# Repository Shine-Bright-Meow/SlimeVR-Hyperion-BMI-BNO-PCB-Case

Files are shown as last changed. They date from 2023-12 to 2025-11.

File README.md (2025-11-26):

> [!NOTE]
>I have a new carrier PCB which is smaller and more optimized than the Hyperion PCB. The entire assembly with case for the 503759 battery is smaller and lighter than the Hyperion one in this repository. The PCB and Case files for meowCarrier PCB can be found here: <https://github.com/Shine-Bright-Meow/meowCarrier/blob/main/README.md>

# SlimeVR Hyperion Multi-IMU BMI BNO Case and PCB

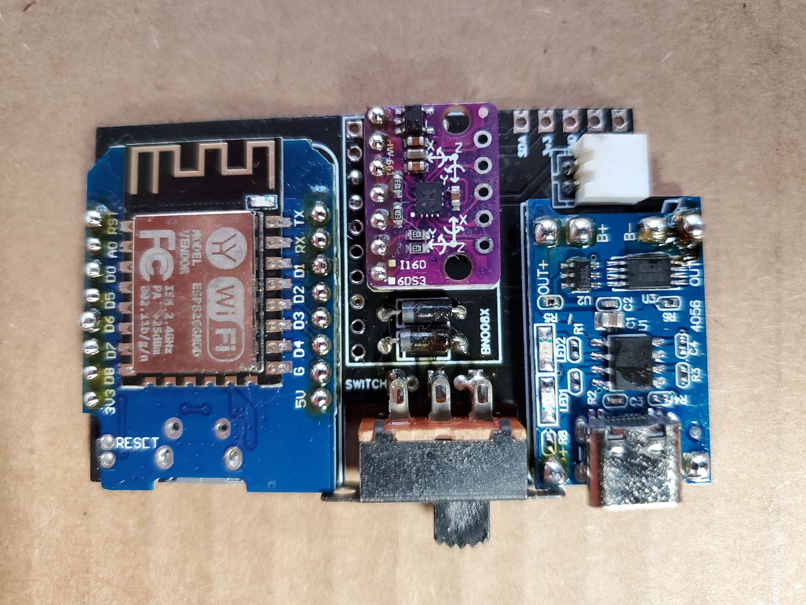
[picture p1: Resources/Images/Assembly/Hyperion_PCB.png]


## Purchasing Guide
### Recommended Components (PCB)
Choose either ICM-45686/LSM6DSV (Performance) and LSM6DSR (Budget/Value) from the list below; not all three.

| Component | Variant | Link |
| --- | --- | --- |
| WeMos D1 Mini | Micro or Type-C (not V4.0.0) | <https://www.aliexpress.us/item/2251832465432818.html> |
| TP4056 | 18650 Micro or Type-C | <https://www.aliexpress.us/item/2251832290307200.html> |
| ICM-45686 | N/A | <https://shop.slimevr.dev/products/slimevr-mumo-breakout-module-v1-icm-45686-qmc6309> |
| LSM6DSR | N/A | <https://moffshop.deyta.de/products/lsm6dsr> |
| LSM6DSV | N/A | <https://moffshop.deyta.de/products/lsm6dsv-module> |
| SS22F32/DPDT 2P2T Switches | N/A | <https://www.aliexpress.us/item/2251832789220847.html> |
| 1/4W Metal Film Resistor | 180**K** | <https://www.aliexpress.us/item/3256803737288214.html> |
| Schottky Rectifier Diode | 1N5817 | <https://www.aliexpress.us/item/2255800018624086.html> |
| Header Pins | 2.54mm | <https://www.aliexpress.us/item/3256805804439042.html> |
| JST PH 2.0mm Connector | Right Angle/Side Entry & 2-Pins (2P) | <https://www.aliexpress.us/item/3256804769340392.html> |
| Lithium Polymer Ion Battery | 503759 with Connector (PH) | <https://www.aliexpress.us/item/3256805125875396.html> |

> [!IMPORTANT]
> Purchase 30% more boards (WeMos D1 Mini, TP4056, and LSM6DSR/LSM6DSV/ICM-45686 than what is needed. There is the possibility that components are dead on arrival or get damaged during assembly/soldering.

> [!NOTE]
> One order of Resistors, Diodes, Header Pins, Switches, and PH 2.0mm Connectors is enough for the entire project.

> [!NOTE]
> The SlimeVR DIY Community recommends buying boards from the following sellers on AliExpress: Win Win, Aitexm, or Tenstar Robot.

> [!NOTE]
> Type-C Ports are more durable. As for charging, USB-C to USB-C Power Delivery doesn't work. Use USB-A to USB-C cables to charge trackers.

> [!IMPORTANT]
> When purchasing components, some have multiple variants on the same product page like Diodes and Resistor. Be sure to select the correct one.

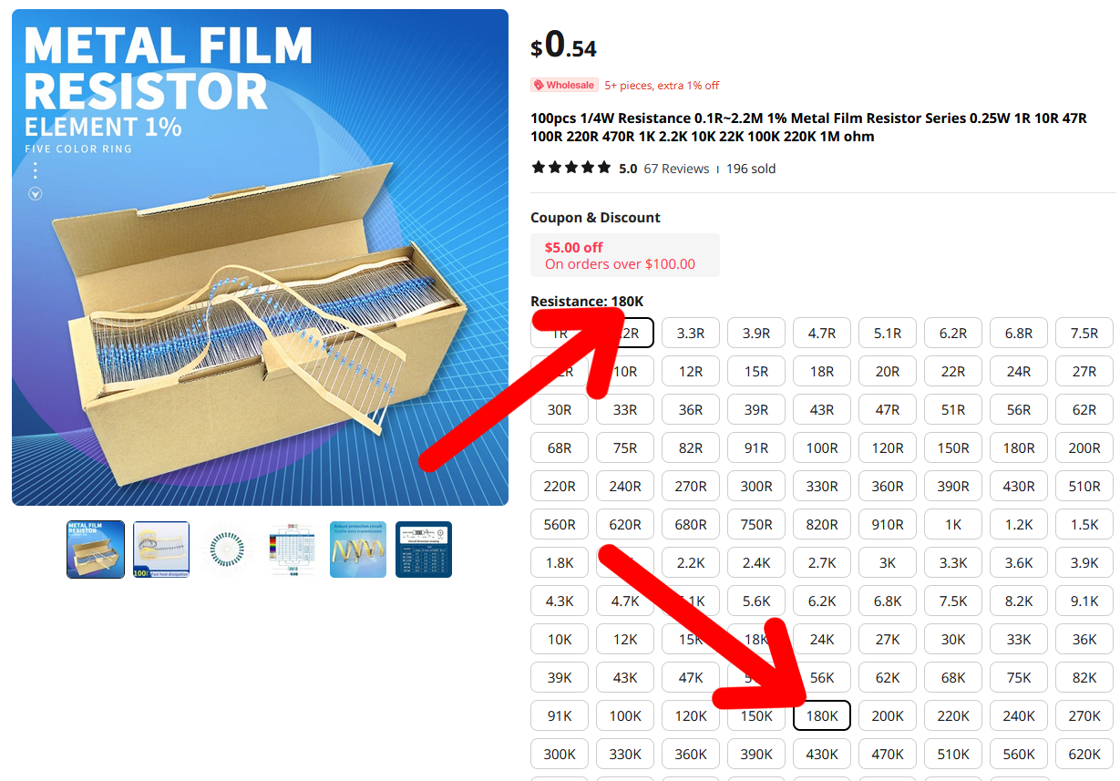
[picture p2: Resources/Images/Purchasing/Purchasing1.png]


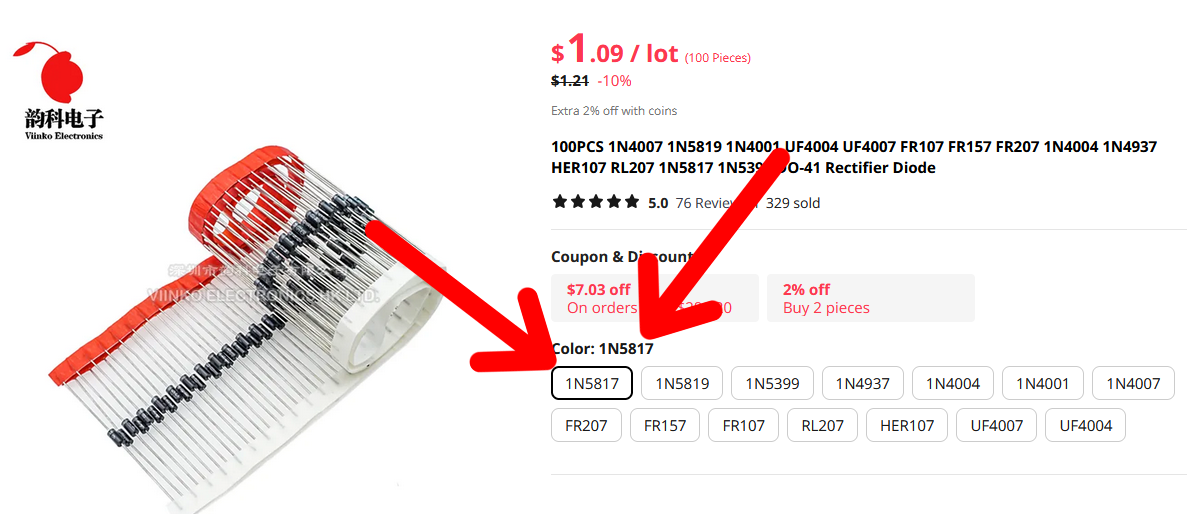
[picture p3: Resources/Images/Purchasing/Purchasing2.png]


> [!TIP]
> In your AliExpress Cart, you can verify that you selected the correct variant of the component here.

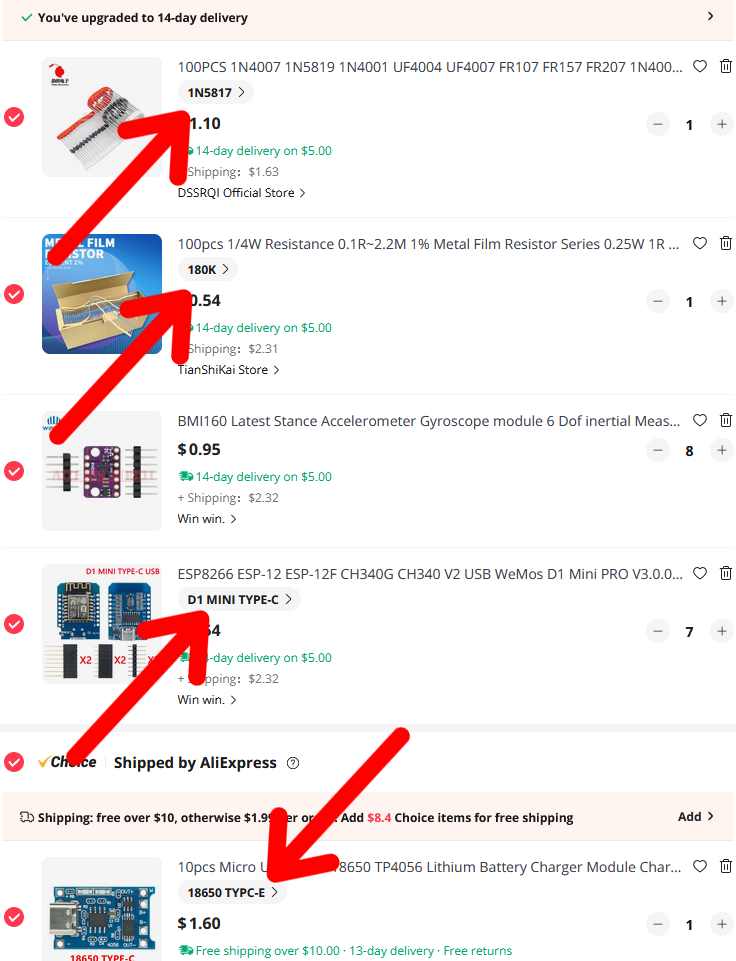
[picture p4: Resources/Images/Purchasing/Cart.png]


### Optional Components (PCB)
| Component | Variant | Link |
| --- | --- | --- |
| JST XH 2.54mm Connector | Right Angle/Side Entry & 4-Pins(LSM6DSR/LSM6DSV/ICM-45686)/5-Pins(BNO085) | <https://www.aliexpress.us/item/2251832822174658.html> |
| JST XH 2.54mm Connector with Female Cable | Right Angle/Side Entry & 4-Pins(LSM6DSR/LSM6DSV/ICM-45686)/5-Pins(BNO085)| <https://www.aliexpress.us/item/2255799934230488.html> |
| Sheathed Wire Cable | 28AWG & 4Cores(LSM6DSR/LSM6DSV/ICM-45686)/5Cores(BNO085) | <https://www.aliexpress.us/item/2255800384086289.html> |

> [!NOTE]
> I recommend using Sheathed Wire Cable and soldering it directly onto the PCB for extensions. (JST XH Connector is not needed for this method) Usually, less connection issues than using connectors.

### Recommended Consumables/Tools
| Component | Variant | Link |
| --- | --- | --- |
| Soldering Iron | Any with BC2 Tip | <https://www.aliexpress.us/item/3256805553022893.html> |
| Solder Sucker| SS-02 or SS-02 Clone | <https://www.aliexpress.us/item/3256805437410900.html> |
| Desoldewring Iron| Choose your electrical outlet | <https://www.aliexpress.us/item/3256804929123151.html> |
| Rosin Flux | Liquid or Gel Type | N/A |

> [!NOTE]
> You will have a much better soldering experience with better tools. These are my recommended (but still on a budget) Soldering Iron and Solder Sucker if you don't have these tools or better already. They will work much better than those Amazon $10-20 soldering kits/iron.

> [!NOTE]
> The Soldering Iron listed requires an USB Type-C Power Delivery charging block of 60W or higher.

### Recommended Components (Case)
| Component | Variant | Link |
| --- | --- | --- |
| Trilancer Elastic Cinch Straps | See note below | <https://www.amazon.com/dp/B099RNRT7Z> |
| GoPro Chest Mount Harness | See note below | <https://www.aliexpress.us/item/3256805774922789.html> |

> [!NOTE]
> 12in works for ankles. 18in for thinner thighs and 24in for thicker thighs. Chest (if not using GoPro Chest Harness) and Hips can be done by doubling up on 18in/24in straps. Choose what you need for your body and how many trackers you are planning to make. 3 Size Combo and either 18in/24in package would be a start.

> [!NOTE]
> There are 2 types of GoPro Chest Mount Harness. One that clips in and the other one fasten by a bolt. Be sure to purchase one one for the case you are 3D Printing.

### Ordering PCBs from JLCPCB
1. Download the Gerber file from [here](https://github.com/Shine-Bright-Meow/SlimeVR-Hyperion-BMI-BNO-PCB-Case/raw/main/PCB/Gerber_PCB_Hyperion%20SlimeVR%20Multi-IMU%20BMI%20BNO.zip).
2. Go to [JLCPCB](https://jlcpcb.com).
3. Click on "Add Gerber File" and upload the zip Gerber file.

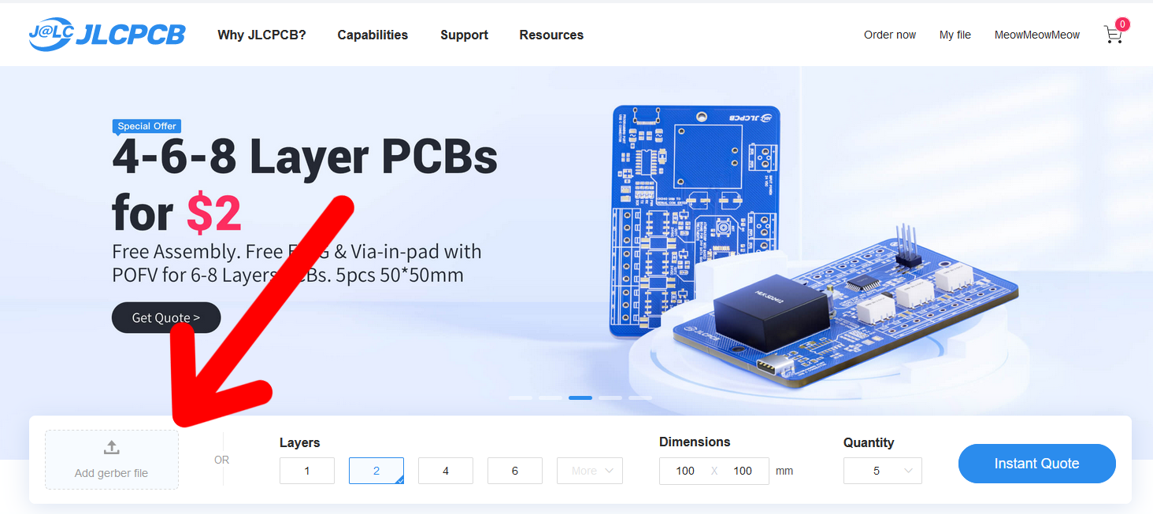
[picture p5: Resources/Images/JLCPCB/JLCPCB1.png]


4. Select the PCB Qty and PCB Color of your choice. Select 1.0 for PCB Thickness and select "Specify a location" for Remove Order Number.

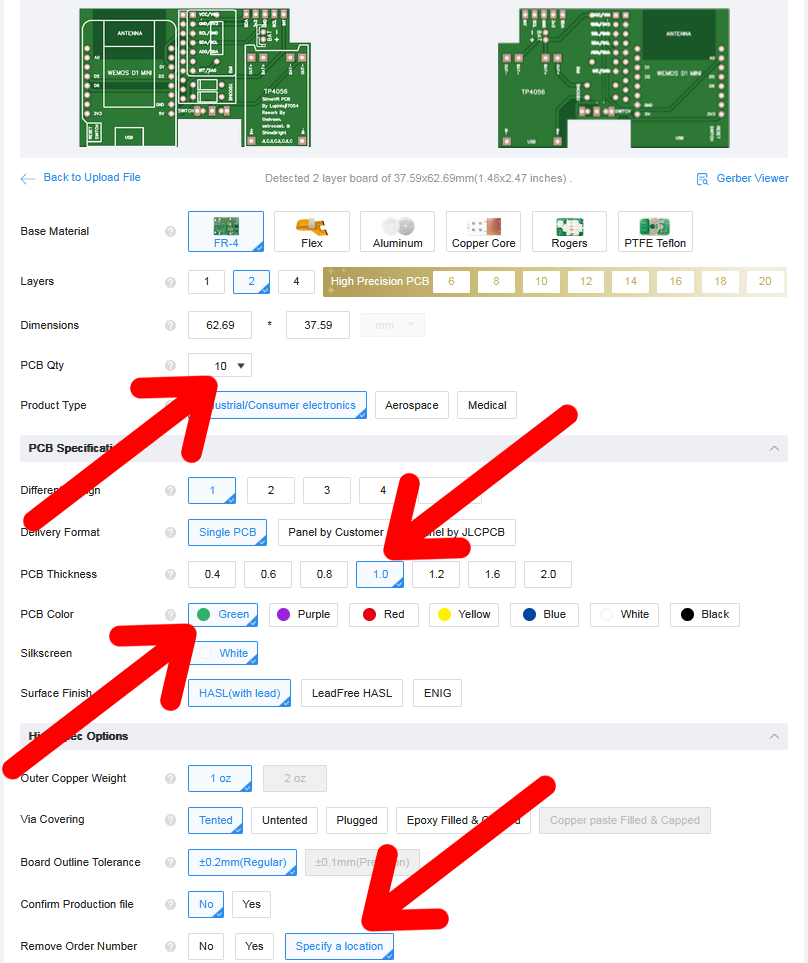
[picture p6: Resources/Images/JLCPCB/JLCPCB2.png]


> [!IMPORTANT]
> Set PCB Thickness to 1.0 if you are using the case from this repository.

> [!NOTE]
> When ordering PCBs, please check if the case recommends a certain thickness it is designed for. For example, the case in this repository and Cheesecake recommend 1.0mm Thickness. If unspecified, the default 1.6mm will do. The case in this repository has loose tolerances incase you ordered the default 1.6mm thickness, it will work okay.

> [!NOTE]
> JLCPCB usually produces Green colored PCB the quickness. Other colors have additional days added.

> [!NOTE]
> For Remove Order Number, when "Specify a location" is selected, it will the order number will be printed at where the text **JLCJLCJLCJLC** is located. In this case, at the bottom of the TP4056 module footprint.
5. Click to View Cart.

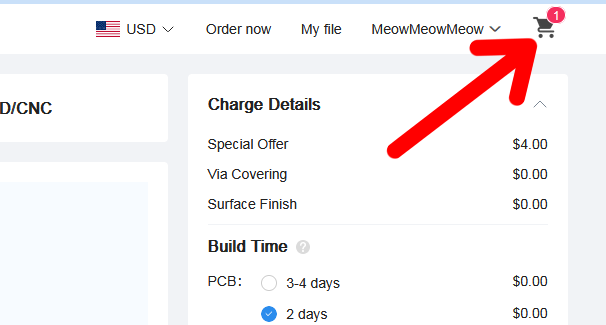
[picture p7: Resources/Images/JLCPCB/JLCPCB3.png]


6. Click Secure Checkout.

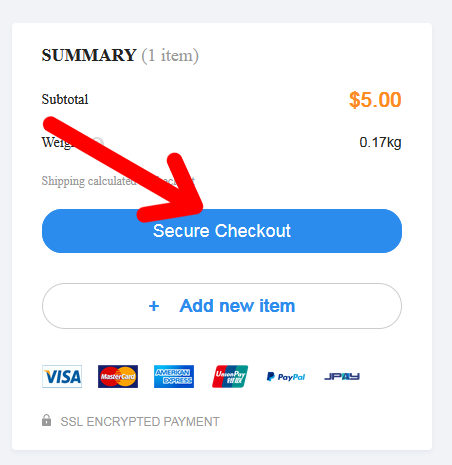
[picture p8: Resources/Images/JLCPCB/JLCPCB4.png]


## Soldering/Assembly Guide

### Written Guide

> [!WARNING]
> Please work at a well ventilated area. It is recommended to use a fume extractor if working indoors. If you do not have one, use a fan to blow fumes/smoke away from your face.

> [!WARNING]
> It is recommended to use eye production. Especially when splitting header pins apart with a cutter and when trimming down header pins and ends of resistors/diodes.

> [!WARNING]
> If working with leaded solder, be sure to wash your hands when you are done including under your fingernails. Wipe down and vacuum the floors and surfaces of your workspace and anything you may have cross-contaminated.

> [!TIP]
> Using external flux (preferably Rosin) will allow solder to flow to automatically flow into the correct area.

> [!TIP]
> A wooden clothespin can be used to hold the boards together while soldering.

> [!NOTE]
> Resistor and Diodes

#### Battery Connector
##### With JST PH 2.0mm 2P Connector
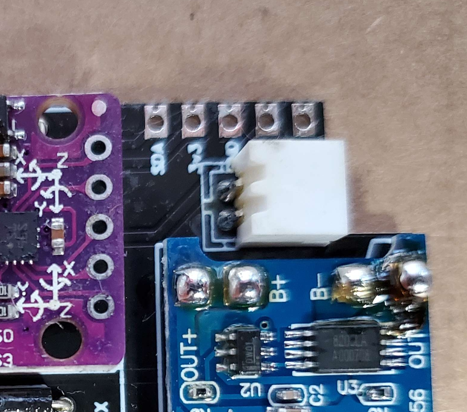
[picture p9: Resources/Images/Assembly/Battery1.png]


1. Place connector as positioned on the photo. The opening should be facing teh cutout and the smooth side should be on top and the slotted side should e against the PCB.
2. Solder the 2 pins in the back.
3. Trim excess length of pins using a flush cutter. Use your wire cutter if you don't have a flush cutter and cut as close the the PCB as you can.

> [!NOTE]
> If you got straight pin connectors, you can bend them 90 degrees, so they will work. There will be a little less pin length sticking out from the back to solder and there is a chance of you snapping them. You should have plenty of connectors incase the pin snaps.

##### Without JST Connector
> [!IMPORTANT]
> This step should be done last after the entire board is assembled and after you verified that the solder joints all look fine.

> [!IMPORTANT]
> Do not solder the battery leads to the holes of the PCB. The angle will put stress on the wire and solder joint and will eventually break off.

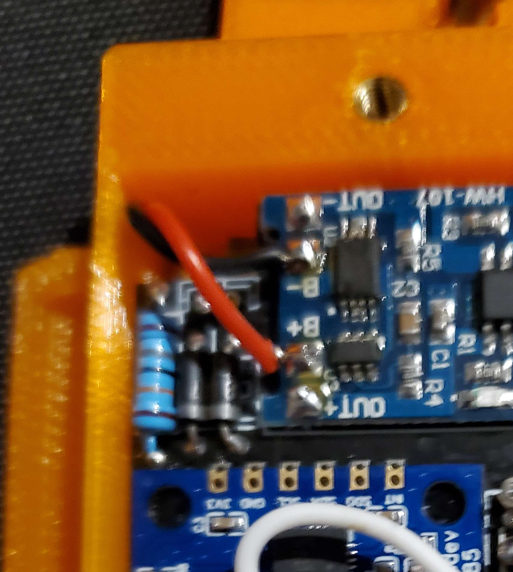
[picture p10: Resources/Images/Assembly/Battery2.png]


1. Strip the battery leads they are not exposed already.

> [!WARNING]
> Do not let the exposed battery leads make contact with each other.

2. Place your soldering iron on the BAT+ pad and melt the solder.
3. Place the **RED** battery lead in the molten solder pad and let it cool off.
4. Repeat the process for the BAT- pad and the **BLACK** battery lead.

##### Diodes
> [!NOTE]
> Make sure the diode is facing the correct direction and has the correct values. It will not be easy to access the diode once you solder the IMU above it.

1. Verify that the diodes are 1N5817. You can find the text on the body.

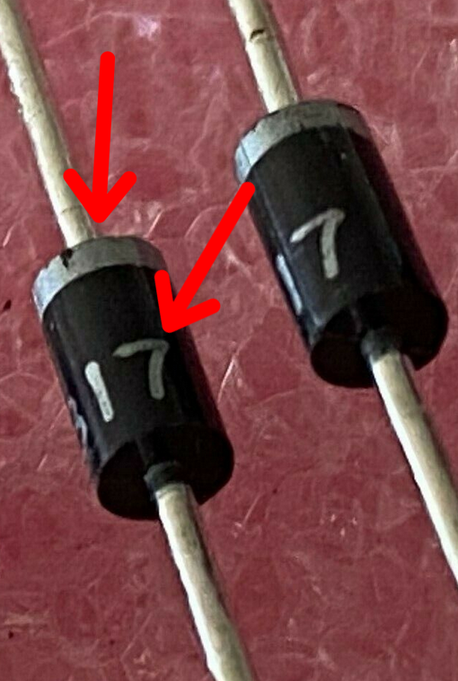
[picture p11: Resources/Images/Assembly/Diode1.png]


2. Place the diode's striped (grey/silver) on the narrow stripe indicated on the silkscreen.

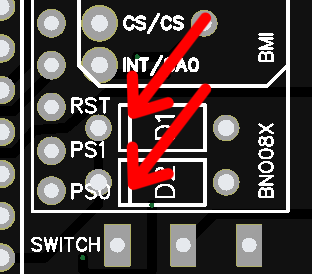
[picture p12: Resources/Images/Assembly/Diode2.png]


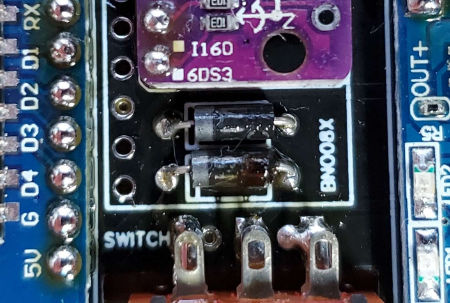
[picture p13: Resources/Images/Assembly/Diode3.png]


3. Bend the ends in 90 degrees, so it is shaped like a staple and place into the through-hole.
4. Pull the excess on the back until diode is flush with the PCB.
5. Solder ends from the back.
6. Repeat for other diode.
7. Trim excess length of pins using a flush cutter. Use your wire cutter if you don't have a flush cutter and cut as close the the PCB as you can.

##### Resistor
> [!NOTE]
> Make sure the resistor is the correct value. It will not be easy to access the resistor once you solder the IMU above it.

1. Verify the resistor is 180K. The first 4 colors should go in this order:
- Brown
- Grey
- Black
- Orange

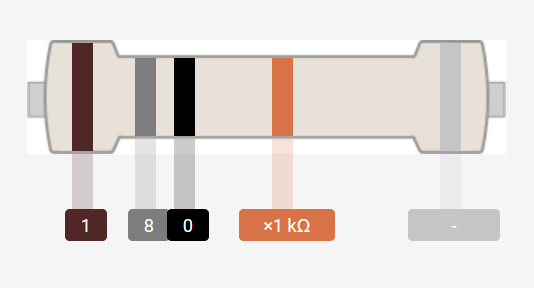
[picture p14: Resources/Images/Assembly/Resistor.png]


2. Bend the ends in 90 degrees, so it is shaped like a staple and place into the through-hole. Resistors are not polarized, so the direction does not matter.
3. Pull the excess on the back until resistor is flush with the PCB.
4. Trim excess length of pins using a flush cutter. Use your wire cutter if you don't have a flush cutter and cut as close the the PCB as you can.

#### Switch

##### DPDT 2P2T/SS22F32

##### SS12D00G3

#### Charging Board (TP4056)

#### IMU (LSM6DSR, LSM6DSV, ICM-45686)

#### MCU (WeMos D1 Mini)

### Video Guide


## Case Guide
The case consists of 3 files: Case, Lid, and Tray.

Printer Settings used:
- **Printer:** Creality CR-10 S5
- **Infill:** 100%
- **No** Rafts or Supports
- **Resolution:** 0.2mm
- **Nozzle:** 0.4mm
- Tested with PLA+ and PETG

> [!TIP]
> For stronger strap loops, print the base/bottom 4mm layers with 0% (solid) infill for just the **case** file. Printing with a zig-zap pattern instead of line will help prevent strap loops from breaking at the weak point where layers join horizontally or vertically. These are done in your Slicer.

### Case
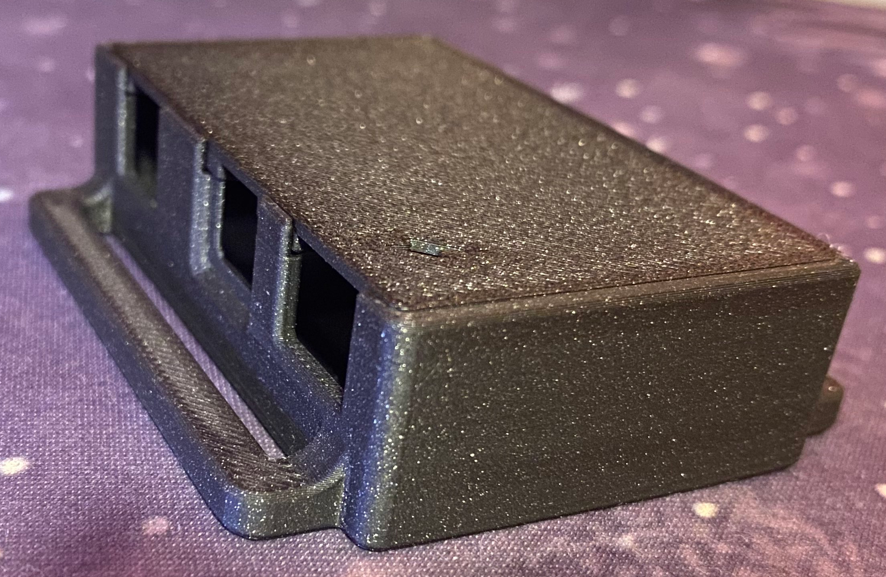
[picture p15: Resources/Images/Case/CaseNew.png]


Case Photo by Higanbana (Meia)

- **No AUX** hasa solid back portion.
- **AUX JST Cutout** has a JST XH 2.54mm 4P-Pin or 5-Pin connector in the back for extension trackers. The non-noted version is for the Multi-IMU version of the PCB and the noted version is for Lupinixx's BMI160 Version.
- **50mm Strap Loops** are the normal for fastening the tracker to your body. You can always use smaller straps.
- **GoPro Chest Harness Adapter** snaps into the harness clip from the top. It is more stable for chest tracking and won't slip down your body.

> [!IMPORTANT]
> GoPro Chest Harness Tracker will have a different IMU rotation than your other trackers.

| Battery | Variant | Link |
| --- | --- | --- |
| 503759 | 50mm Strap Loops / No AUX | [Hyperion_Lite_Case_503759.stl](https://github.com/Shine-Bright-Meow/SlimeVR-Hyperion-BMI-BNO-PCB-Case/raw/main/Case/STL/Hyperion_Lite_Case_503759.stl)|
| 503759 | 50mm Strap Loops / AUX JST Cutout | [Hyperion_Lite_Case_503759_AUX.stl](https://github.com/Shine-Bright-Meow/SlimeVR-Hyperion-BMI-BNO-PCB-Case/raw/main/Case/STL/Hyperion_Lite_Case_503759_AUX.stl) |
| 503759 | 50mm Strap Loops / AUX JST Cutout (Lupinixx) | [Hyperion_Lite_Case_503759_AUX_Lupinixx.stl](https://github.com/Shine-Bright-Meow/SlimeVR-Hyperion-BMI-BNO-PCB-Case/raw/main/Case/STL/Hyperion_Lite_Case_503759_AUX_Lupinixx.stl) |
| 503759 | GoPro Chest Harness Adapter / No AUX | [Hyperion_Lite_Case_503759_GoPro.stl](https://github.com/Shine-Bright-Meow/SlimeVR-Hyperion-BMI-BNO-PCB-Case/raw/main/Case/STL/Hyperion_Lite_Case_503759_GoPro.stl) |
| 804040 | 50mm Strap Loops / No AUX | [Hyperion_Lite_Case_804040.stl](https://github.com/Shine-Bright-Meow/SlimeVR-Hyperion-BMI-BNO-PCB-Case/raw/main/Case/STL/Hyperion_Lite_Case_804040.stl)|
| 804040 | 50mm Strap Loops / AUX JST Cutout | [Hyperion_Lite_Case_804040_AUX.stl](https://github.com/Shine-Bright-Meow/SlimeVR-Hyperion-BMI-BNO-PCB-Case/raw/main/Case/STL/Hyperion_Lite_Case_804040_AUX.stl) |
| 804040 | 50mm Strap Loops / AUX JST Cutout (Lupinixx) | [Hyperion_Lite_Case_804040_AUX_Lupinixx.stl](https://github.com/Shine-Bright-Meow/SlimeVR-Hyperion-BMI-BNO-PCB-Case/raw/main/Case/STL/Hyperion_Lite_Case_804040_AUX_Lupinixx.stl) |
| 804040 | GoPro Chest Harness Adapter / No AUX | [Hyperion_Lite_Case_804040_GoPro.stl](https://github.com/Shine-Bright-Meow/SlimeVR-Hyperion-BMI-BNO-PCB-Case/raw/main/Case/STL/Hyperion_Lite_Case_804040_GoPro.stl) |
| 804040 and 503759 | GoPro Chest Harness Adapter alternative mount/ No AUX | https://www.printables.com/model/1362426-hyperion-lite-slimevr-case-with-screw-chest-gopro/files |

### Lid
- No AUX / AUX 5mm Hole has a solid back portion. Use this Lid for the **AUX 5mmm Hole** case also.
- AUX has a notch cutout giving the JST XH 2.54mm 4P-Pin or 5-Pin connector a bit of additional height. The non-noted version is for the Multi-IMU version of the PCB and the noted version is for Lupinixx's BMI160 Version.
  
| Battery | Variant | Link |
| --- | --- | --- |
| 503759 | No AUX | [Hyperion_Lite_Lid_503759.stl](https://github.com/Shine-Bright-Meow/SlimeVR-Hyperion-BMI-BNO-PCB-Case/raw/main/Case/STL/Hyperion_Lite_Lid_503759.stl) |
| 503759 | AUX JST Cutout | [Hyperion_Lite_Lid_503759_AUX.stl](https://github.com/Shine-Bright-Meow/SlimeVR-Hyperion-BMI-BNO-PCB-Case/raw/main/Case/STL/Hyperion_Lite_Lid_503759_AUX.stl) |
| 503759 | AUX JST Cutout (Lupinixx) | [Hyperion_Lite_Lid_503759_AUX_Lupinixx.stl](https://github.com/Shine-Bright-Meow/SlimeVR-Hyperion-BMI-BNO-PCB-Case/raw/main/Case/STL/Hyperion_Lite_Lid_503759_AUX_Lupinixx.stl) |
| 804040 | No AUX | [Hyperion_Lite_Lid_804040.stl](https://github.com/Shine-Bright-Meow/SlimeVR-Hyperion-BMI-BNO-PCB-Case/raw/main/Case/STL/Hyperion_Lite_Lid_804040.stl) |
| 804040 | AUX JST Cutout | [Hyperion_Lite_Lid_804040_AUX.stl](https://github.com/Shine-Bright-Meow/SlimeVR-Hyperion-BMI-BNO-PCB-Case/raw/main/Case/STL/Hyperion_Lite_Lid_804040_AUX.stl) |
| 804040 | AUX JST Cutout (Lupinixx) | [Hyperion_Lite_Lid_804040_AUX_Lupinixx.stl](https://github.com/Shine-Bright-Meow/SlimeVR-Hyperion-BMI-BNO-PCB-Case/raw/main/Case/STL/Hyperion_Lite_Lid_804040_AUX_Lupinixx.stl) |

### Tray
- SS22F32 is a flat tray since the switch is supported by wedging against the PCB and Case.
- SS12D00G3 tray has a craddle for the switch to go into. It prevents the pins from being bent when turning on or off the tracker.
  
| Battery | Switch | Link |
| --- | --- | --- |
| 503759 | SS22F32 | [Hyperion_Lite_Tray_503759_SS22F32.stl](https://github.com/Shine-Bright-Meow/SlimeVR-Hyperion-BMI-BNO-PCB-Case/raw/main/Case/STL/Hyperion_Lite_Tray_503759_SS22F32.stl)|
| 503759 | SS12D00G3| [Hyperion_Lite_Tray_503759_SS12D00G3.stl](https://github.com/Shine-Bright-Meow/SlimeVR-Hyperion-BMI-BNO-PCB-Case/raw/main/Case/STL/Hyperion_Lite_Tray_503759_SS12D00G3.stl) |
| 804040 | SS22F32 | [Hyperion_Lite_Tray_804040_SS22F32.stl](https://github.com/Shine-Bright-Meow/SlimeVR-Hyperion-BMI-BNO-PCB-Case/raw/main/Case/STL/Hyperion_Lite_Tray_804040_SS22F32.stl)|
| 804040 | SS12D00G3| [Hyperion_Lite_Tray_804040_SS12D00G3.stl](https://github.com/Shine-Bright-Meow/SlimeVR-Hyperion-BMI-BNO-PCB-Case/raw/main/Case/STL/Hyperion_Lite_Tray_804040_SS12D00G3.stl) |

## Troubleshooting

Join [SlimeVR Discord](https://discord.gg/SlimeVR) and ask in either the #technical-support or #DIY channels. It would be helpful for you to provide a description of your issue, photos of your soldering (front & back), and a log output from Settings > Serial Console with your tracker plugged into your computer via data USB cable into your WeMos D1 Port (non-charging). You will need to press the **Reboot** button to get the complete log.

### Using a Multimeter

1. Go to the drawing located [here](https://oshwlab.com/Newbie2620/slimevr-multi-imu-bmi-bno).
2. Scroll down to the PCB section and click the Open in Editor button.

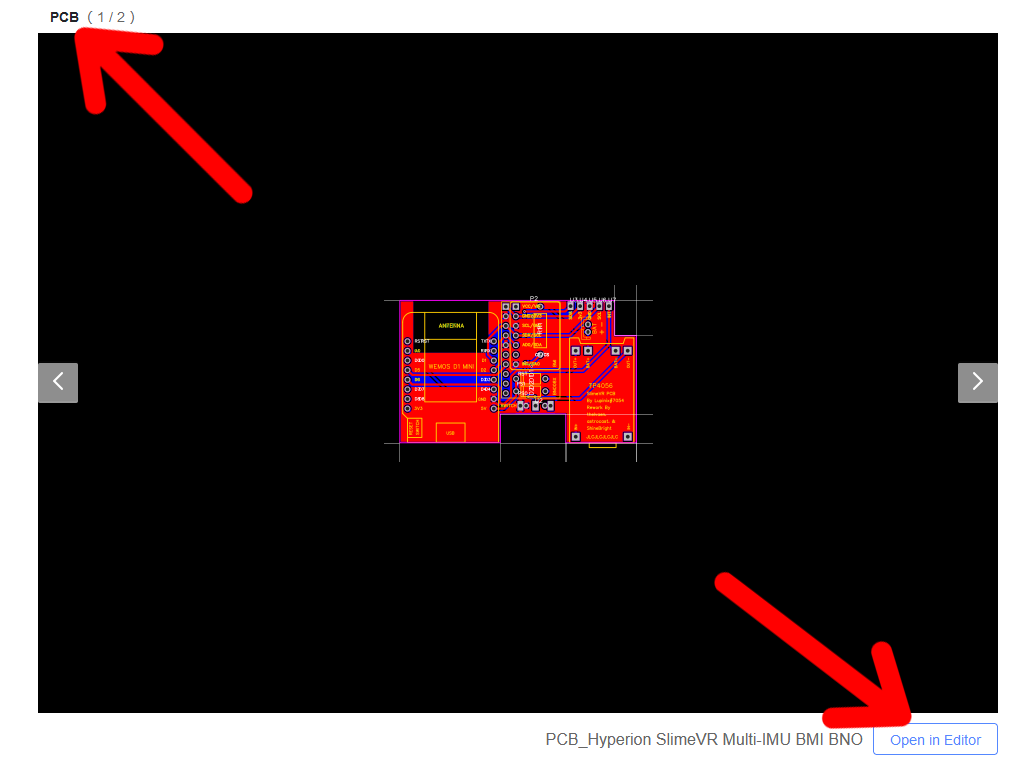
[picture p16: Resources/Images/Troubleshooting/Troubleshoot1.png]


3. Mouseover each pad and see which pads they are also connected to.

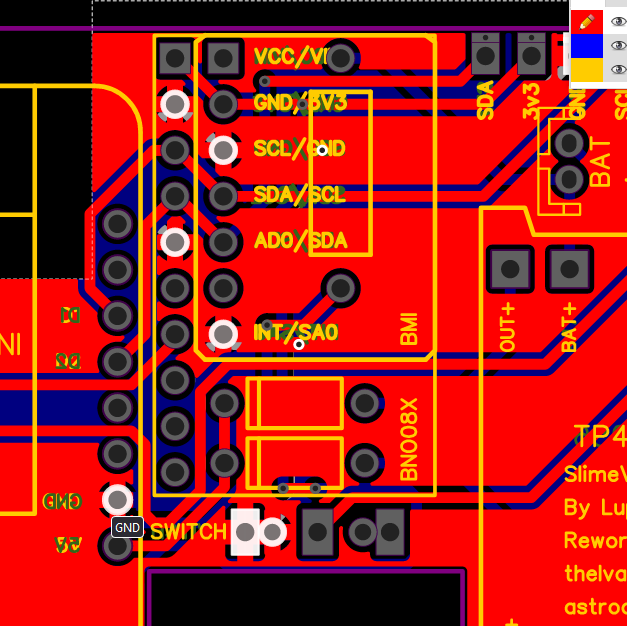
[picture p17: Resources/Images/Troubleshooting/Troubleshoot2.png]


4. Set your multimeter to continuity mode.

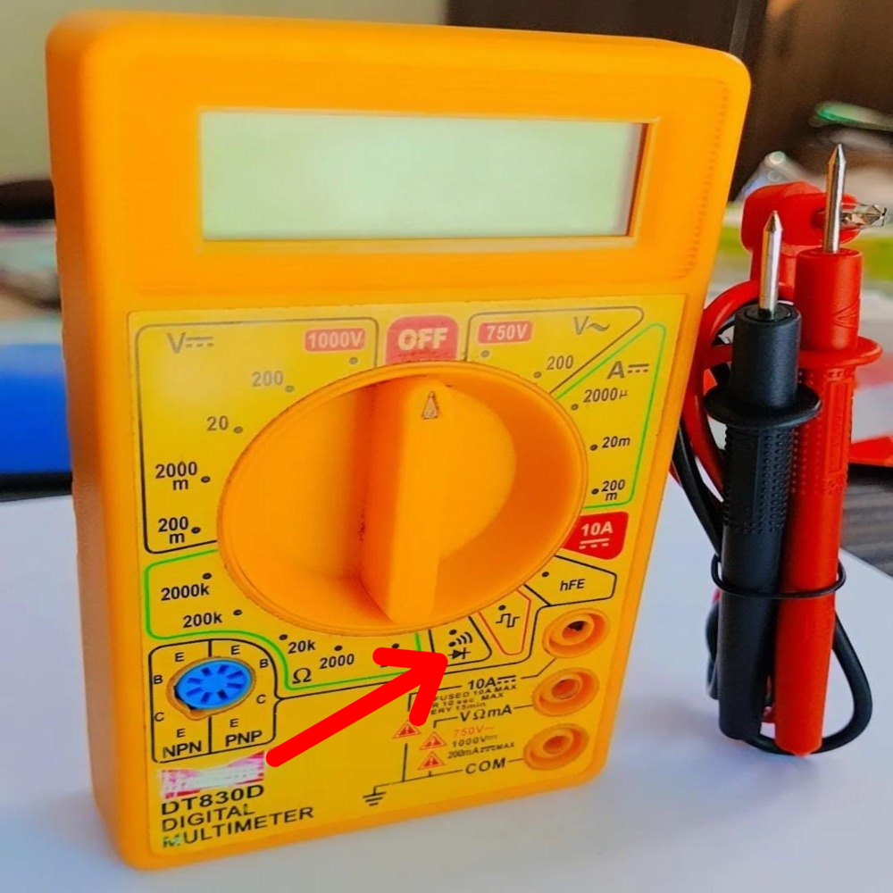
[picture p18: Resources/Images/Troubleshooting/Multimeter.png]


5. Test for continuity between the pad you have highlighted with your mouse and every pad that is connected to it. Do this for every trace.

> [!NOTE]
> Also, test the switch for continuity in the on position.

Left and Middle Pins on SS12D00G3 Switch:

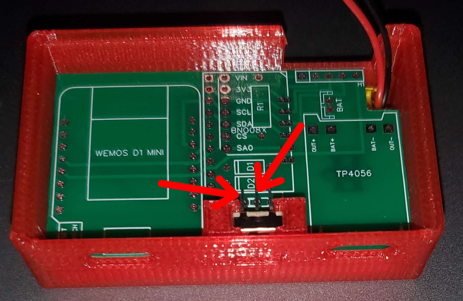
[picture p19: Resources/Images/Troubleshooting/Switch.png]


Left and Middle Pins of the bottom row (against the PCB) for DPDT 2P2T/SS22F32 Switch:

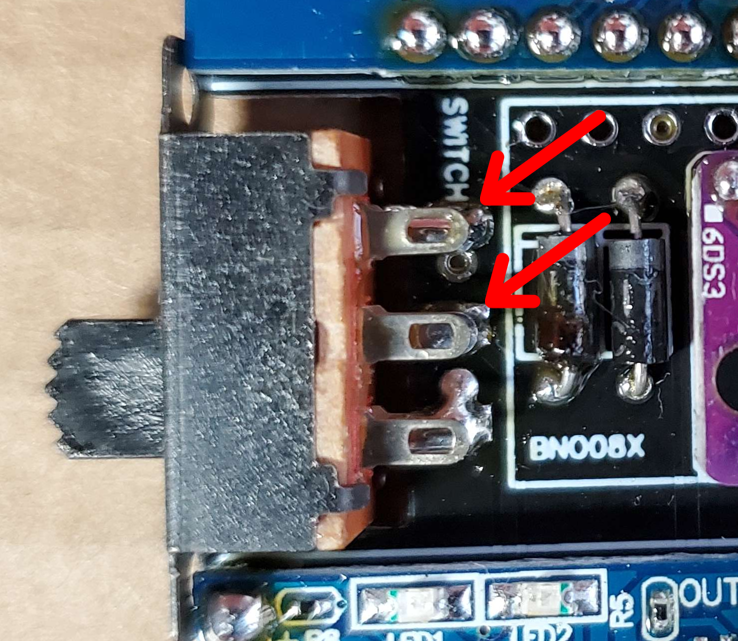
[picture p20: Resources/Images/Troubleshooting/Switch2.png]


## Contribute
Feel free to create a pull request to this repository or mention me in SlimeVR's Discord #DIY channel (Do not DM me, it will go to my Message Request and I will not reply to you there) for improvement ideas or your modifications of the source files below or to the guide above.

### Source Files
| Component | Link |
| --- | --- |
| PCB | <https://oshwlab.com/Newbie2620/slimevr-multi-imu-bmi-bno> |
| Case - 503759 | Fusion 360 Files - [Hyperion_Lite_503759.f3d](https://github.com/Shine-Bright-Meow/SlimeVR-Hyperion-BMI-BNO-PCB-Case/raw/main/Case/Fusion_360/Hyperion_Lite_503759.f3d) |
| Case - 804040 | Fusion 360 Files - [Hyperion_Lite_804040.f3d](https://github.com/Shine-Bright-Meow/SlimeVR-Hyperion-BMI-BNO-PCB-Case/raw/main/Case/Fusion_360/Hyperion_Lite_804040.f3d) |

## Credit
| Contributor | Description | Link |
| --- | --- | --- |
| Smeltie | Original Concept of the Hyperion Case | <https://github.com/Smeltie/Hyperion> |
| Lupinixx | Original BMI160 PCB Design and SS12D00G3 Tray used in this repository | <https://github.com/Lupinixx/SlimeVR-Hyperion-BMI160-PCB> |
| Tmandel | BNO085 modifications to the original PCB | <https://oshwlab.com/tmandel/slimevr-hyperion-503759-bno085> |
| Astrocast123 | Improvement on Tmandel's BNO08X PCB revision | <https://oshwlab.com/astrocast123/SlimeVR-Hyperion-BNO08X> |
| nethesem/Adamant IT | Video with Commentary | <https://www.youtube.com/@AdamantIT2> |
| Shine Bright | Improvements to PCB, new case design, and this guide write-up in this repository | <https://github.com/Shine-Bright-Meow/SlimeVR-Hyperion-BMI-BNO-PCB-Case> |

Thank you to those who printed my case and provided feedback: Topaz, Ventidge, Higanbana (Meia), and Plank.

## Licence
This project is licensed under the MIT licence.

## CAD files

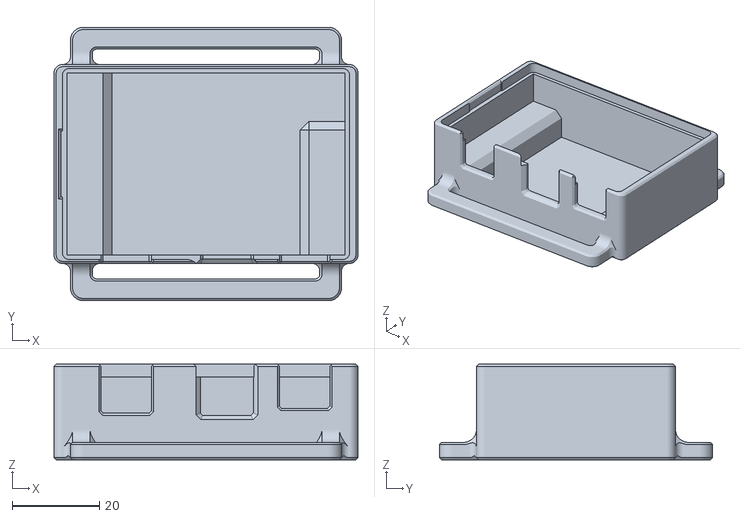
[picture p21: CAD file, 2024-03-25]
Case/STL/Hyperion_Lite_Case_804040.stl
69.5 x 62.5 x 21.9

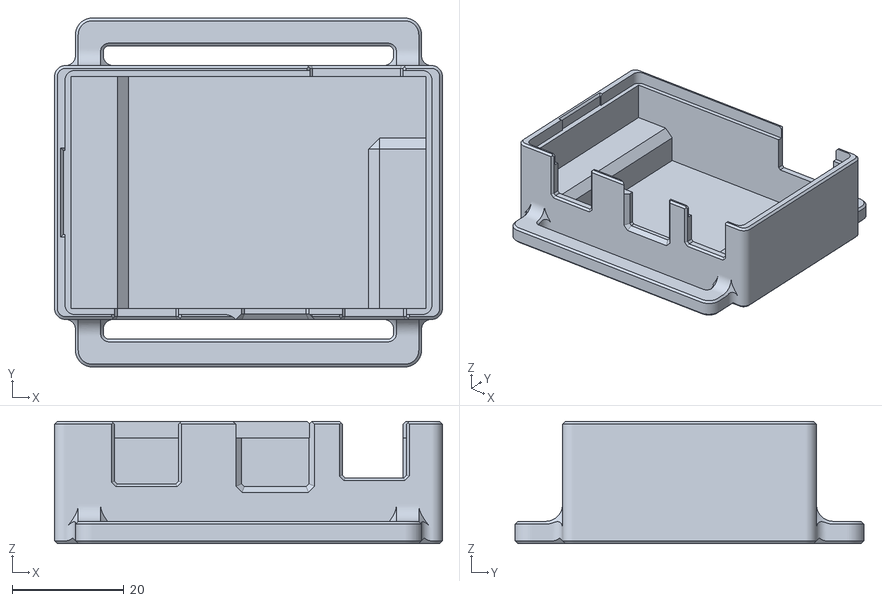
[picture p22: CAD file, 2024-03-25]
Case/STL/Hyperion_Lite_Case_804040_AUX.stl
69.5 x 62.5 x 21.9

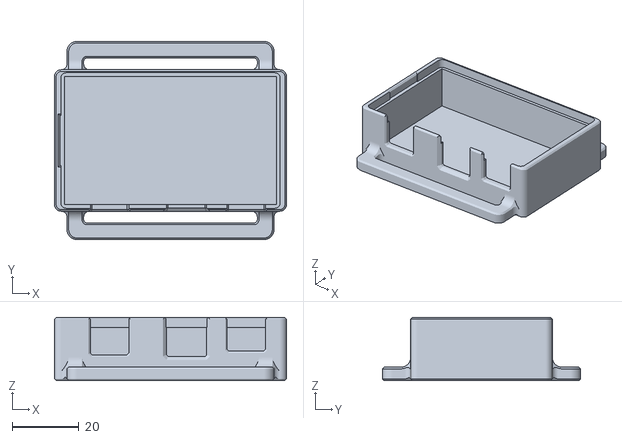
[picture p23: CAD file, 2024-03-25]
Case/STL/Hyperion_Lite_Case_503759.stl
69.5 x 59.4 x 18.9

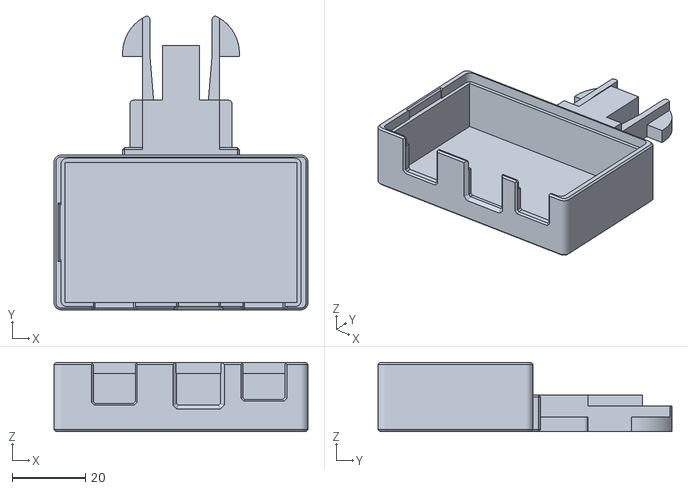
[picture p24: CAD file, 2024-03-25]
Case/STL/Hyperion_Lite_Case_503759_GoPro.stl
69.5 x 80.4 x 18.9

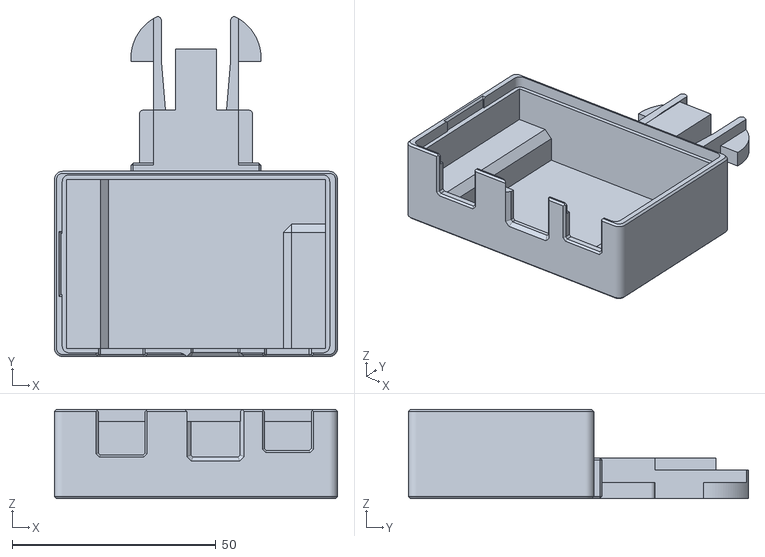
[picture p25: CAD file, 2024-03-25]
Case/STL/Hyperion_Lite_Case_804040_GoPro.stl
69.5 x 83.5 x 21.9

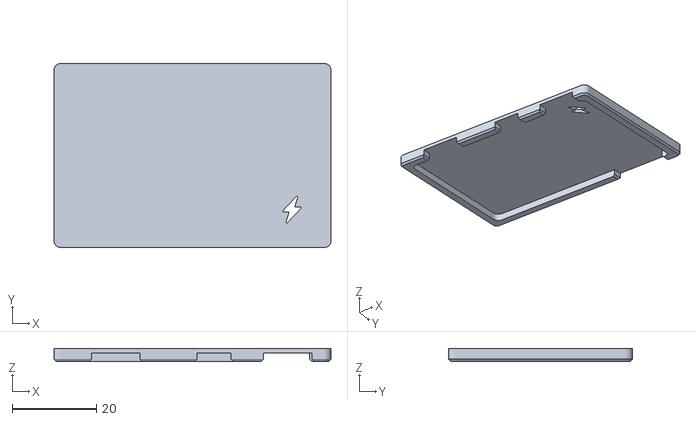
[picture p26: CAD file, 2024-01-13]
Case/STL/Hyperion_Lite_Lid_804040_AUX.stl
65.7 x 43.7 x 3.00

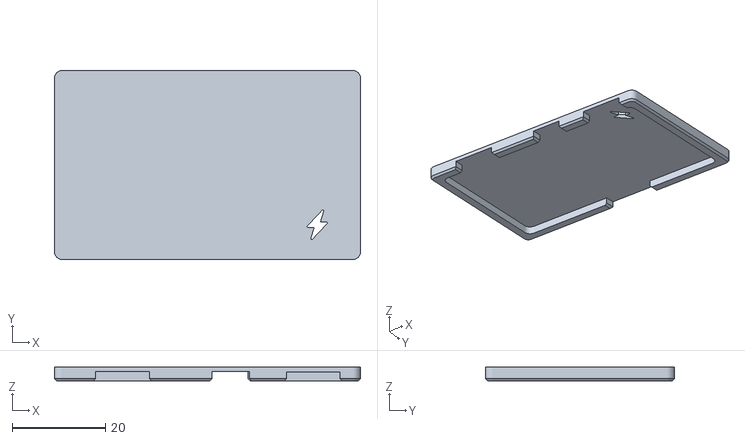
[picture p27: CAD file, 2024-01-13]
Case/STL/Hyperion_Lite_Lid_503759_AUX_Lupinixx.stl
65.7 x 40.6 x 3.00

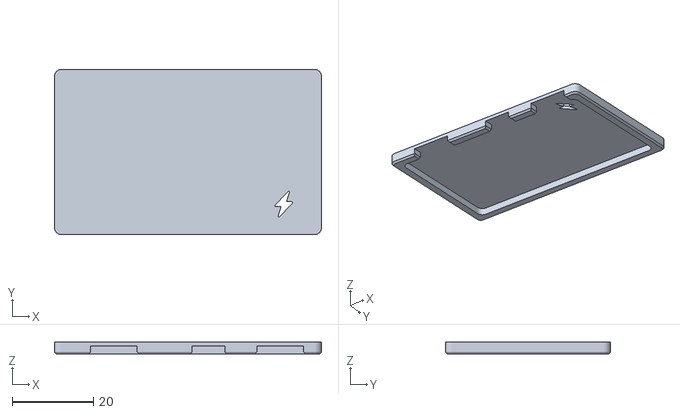
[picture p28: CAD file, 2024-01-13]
Case/STL/Hyperion_Lite_Lid_503759.stl
65.7 x 40.6 x 3.00

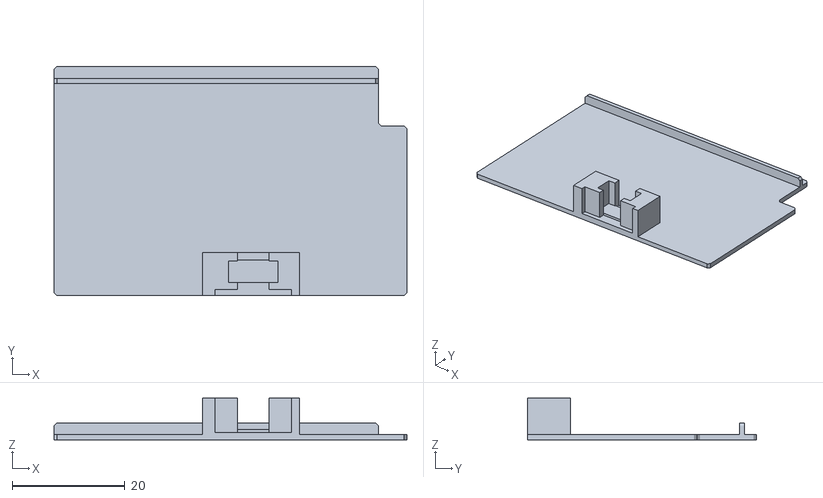
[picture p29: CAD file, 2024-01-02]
Case/STL/Hyperion_Lite_Tray_804040_SS12D00G3.stl
62.5 x 40.5 x 7.40

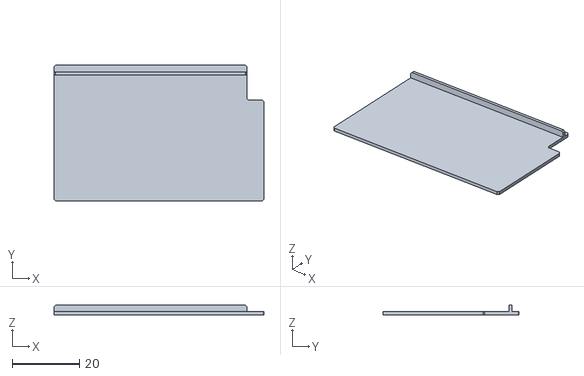
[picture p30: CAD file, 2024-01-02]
Case/STL/Hyperion_Lite_Tray_804040_SS22F32.stl
62.5 x 40.5 x 3.00

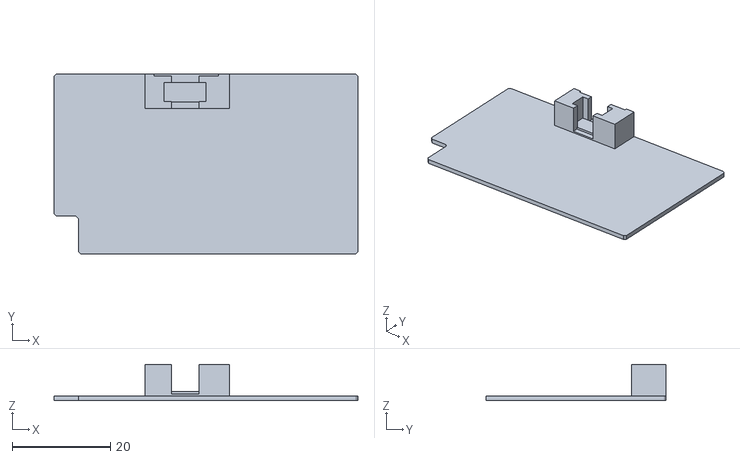
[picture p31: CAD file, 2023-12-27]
Case/STL/Hyperion_Lite_Tray_503759_SS12D00G3.stl
61.9 x 36.7 x 7.40

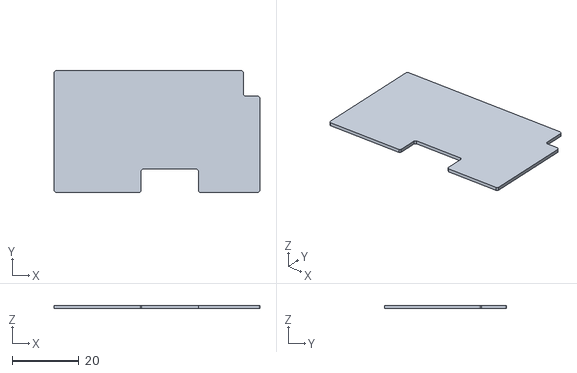
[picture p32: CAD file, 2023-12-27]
Case/STL/Hyperion_Lite_Tray_503759_SS22F32.stl
61.9 x 36.8 x 1.00

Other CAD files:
Case/STL/Hyperion_Lite_Case_503759_AUX_Lupinixx.stl
Case/STL/Hyperion_Lite_Case_804040_AUX_Lupinixx.stl
Case/STL/Hyperion_Lite_Case_503759_AUX.stl
Case/STL/Hyperion_Lite_Lid_804040.stl
Case/STL/Hyperion_Lite_Lid_804040_AUX_Lupinixx.stl
Case/STL/Hyperion_Lite_Lid_503759_AUX.stl
Case/Fusion_360/Hyperion_Lite_503759.f3d
Case/Fusion_360/Hyperion_Lite_804040.f3d

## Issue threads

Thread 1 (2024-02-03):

Is there an STL file for the AUX sensor case?

hnktn, 2024-02-03:
Hello,

I am interested in obtaining the STL file for the AUX sensor case. Does the repository contain the 3D model file for the case used with the AUX sensor? If so, could you please provide a link to download it?

Thank you in advance for your assistance.

ShineBrightMeow, 2024-02-03:
Hi Hnktn, I don't have an AUX case. There are several decent ones out there already. Check out: <https://github.com/Lixulia/Arcturus> and <https://www.printables.com/model/647109-minted-arcturus-slimevr-diy-standard-parts/files>

hnktn, 2024-02-04:
Hi ShineBrightMeow,

Thank you for your response and the provided links. I appreciate your help. I will check out the resources you shared to find an AUX case that suits my needs.

Closed 2024-02-04.

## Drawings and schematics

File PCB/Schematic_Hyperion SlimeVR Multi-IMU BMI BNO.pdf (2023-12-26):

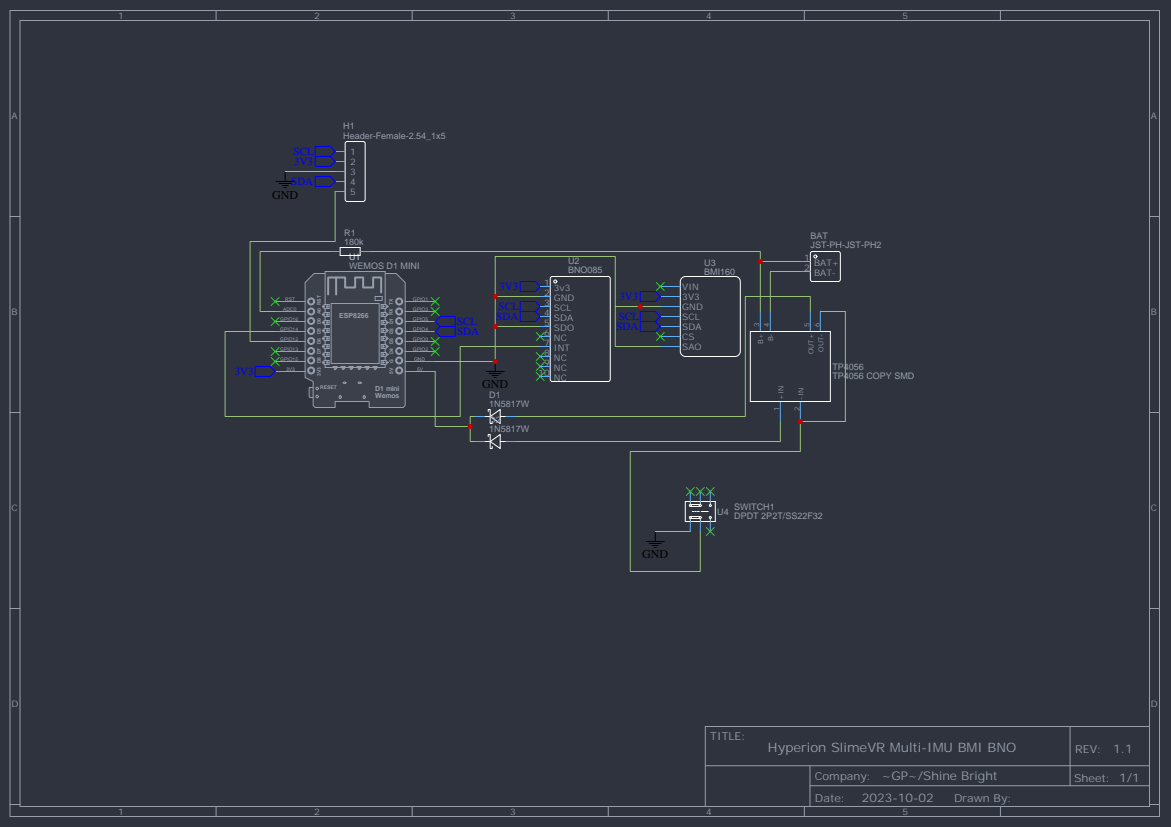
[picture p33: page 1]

Company: ~GP~/Shine Bright

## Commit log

2023-12-27 Strap Loops Optimization
    [Hyperion_Lite_Case_503759.stl, Hyperion_Lite_Case_503759_AUX.stl]
2023-12-28 Case Guide Table
2023-12-30 Looser Tolerances
    [Hyperion_Lite_Case_503759.stl, Hyperion_Lite_Case_503759_AUX.stl, Hyperion_Lite_Lid_503759.stl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]
2023-12-30 Chamfered lid for easier initial entry
    [Hyperion_Lite_Lid_503759.stl, Hyperion_Lite_Lid_503759_AUX.stl]
2023-12-30 Lid Optimization
    [Hyperion_Lite_Lid_503759.stl, Hyperion_Lite_Lid_503759_AUX.stl]
2023-12-31 Early release of GoPro Adapter Case
    [Hyperion_Lite_Case_503759_GoPro.stl]
2023-12-31 Minor bug fix
    [Hyperion_Lite_Case_503759_GoPro.stl]
2023-12-31 Chamfered sharp edges of GoPro Adapater
    [Hyperion_Lite_Case_503759_GoPro.stl]
2024-01-01 Test files for Lupinixx PCB AUX Cutout
    [Hyperion_Lite_Case_503759_AUX_Lupinixx.stl, Hyperion_Lite_Lid_503759_AUX_Lupinixx.stl]
2024-01-01 Wider Clearance for Straps
    [Hyperion_Lite_Case_503759.stl, Hyperion_Lite_Case_503759_AUX.stl]
2024-01-02 804040 Files
    [Hyperion_Lite_Case_804040.stl, Hyperion_Lite_Case_804040_AUX.stl, Hyperion_Lite_Case_804040_AUX_Lupinixx.stl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]
2024-01-02 Centered Charging Port
    [Hyperion_Lite_Case_503759.stl, Hyperion_Lite_Case_503759_AUX.stl, Hyperion_Lite_Case_503759_AUX_Lupinixx.stl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]
2024-01-02 Centered Charging Port better
2024-01-06 Battery Center of Gravity
    [Hyperion_Lite_Case_804040.stl, Hyperion_Lite_Case_804040_AUX.stl, Hyperion_Lite_Case_804040_AUX_Lupinixx.stl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]
2024-01-13 Centered TP4056 Port Better
    [Hyperion_Lite_Case_503759.stl, Hyperion_Lite_Case_503759_AUX.stl, Hyperion_Lite_Case_503759_AUX_Lupinixx.stl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]
2024-01-13 Centered TP4056 Port Better and increased battery spacing
    [Hyperion_Lite_Case_804040.stl, Hyperion_Lite_Case_804040_AUX.stl, Hyperion_Lite_Case_804040_AUX_Lupinixx.stl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]
2024-01-21 Strap Loop Upgrade
    Strongest Strap Loops out of all of the Hyperion Cases
    [Hyperion_Lite_503759.f3d, Hyperion_Lite_804040.f3d]
2024-01-21 Strap Loop Upgrade
    [Hyperion_Lite_804040.f3d]
2024-01-21 Strongest Strap Loops out of all Hyperion Cases
    [Hyperion_Lite_Case_503759.stl, Hyperion_Lite_Case_503759_AUX.stl, Hyperion_Lite_Case_503759_AUX_Lupinixx.stl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]
2024-01-21 Tips for Stronger Strap Loops
2024-01-28 Fillet for even stronger strap loops
    [Hyperion_Lite_Case_503759.stl, Hyperion_Lite_Case_503759_AUX.stl, Hyperion_Lite_Case_503759_AUX_Lupinixx.stl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]
2024-02-29 Swap Battery Pins
2024-03-25 Updated Switch cutout
    [Hyperion_Lite_503759.f3d, Hyperion_Lite_804040.f3d]
2024-03-25 Updated Switch Cutout & Improved Strap Loops
    [Hyperion_Lite_Case_503759.stl, Hyperion_Lite_Case_503759_AUX.stl, Hyperion_Lite_Case_503759_AUX_Lupinixx.stl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]
2024-03-30 Polarity Symbols above JST Footprint
2024-04-20 Standardized PH though-holes
2025-09-05 docs: IMU Update
2025-11-26 Update README.md
    added alternative mounts for gopro case
